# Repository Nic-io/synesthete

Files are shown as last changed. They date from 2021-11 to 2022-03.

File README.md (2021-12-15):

# Synesthete

## Listen to your eyes
A Zephyr RTOS project

This project aims at creating a Eurorack module on the base of Zephyr.

The main functionality is to produce a waveform generated by drawing on
a touch screen.

## Environment 
For a quick start you can use the pre made devcontainer by running
the script here : https://github.com/Nic-io/vittles

## Build

Run ```west build -b nucleo_f446re -- -DSHIELD=adafruit_2_8_tft_touch_v2```

## Hardware
SVG Panel :

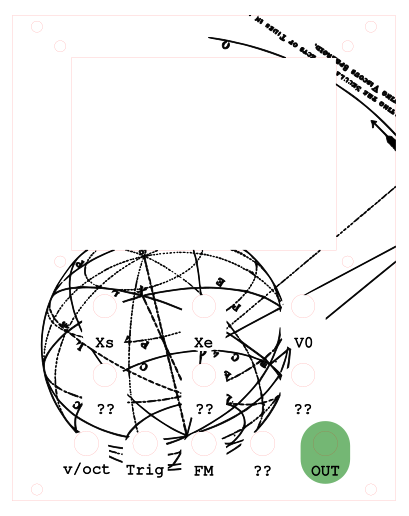
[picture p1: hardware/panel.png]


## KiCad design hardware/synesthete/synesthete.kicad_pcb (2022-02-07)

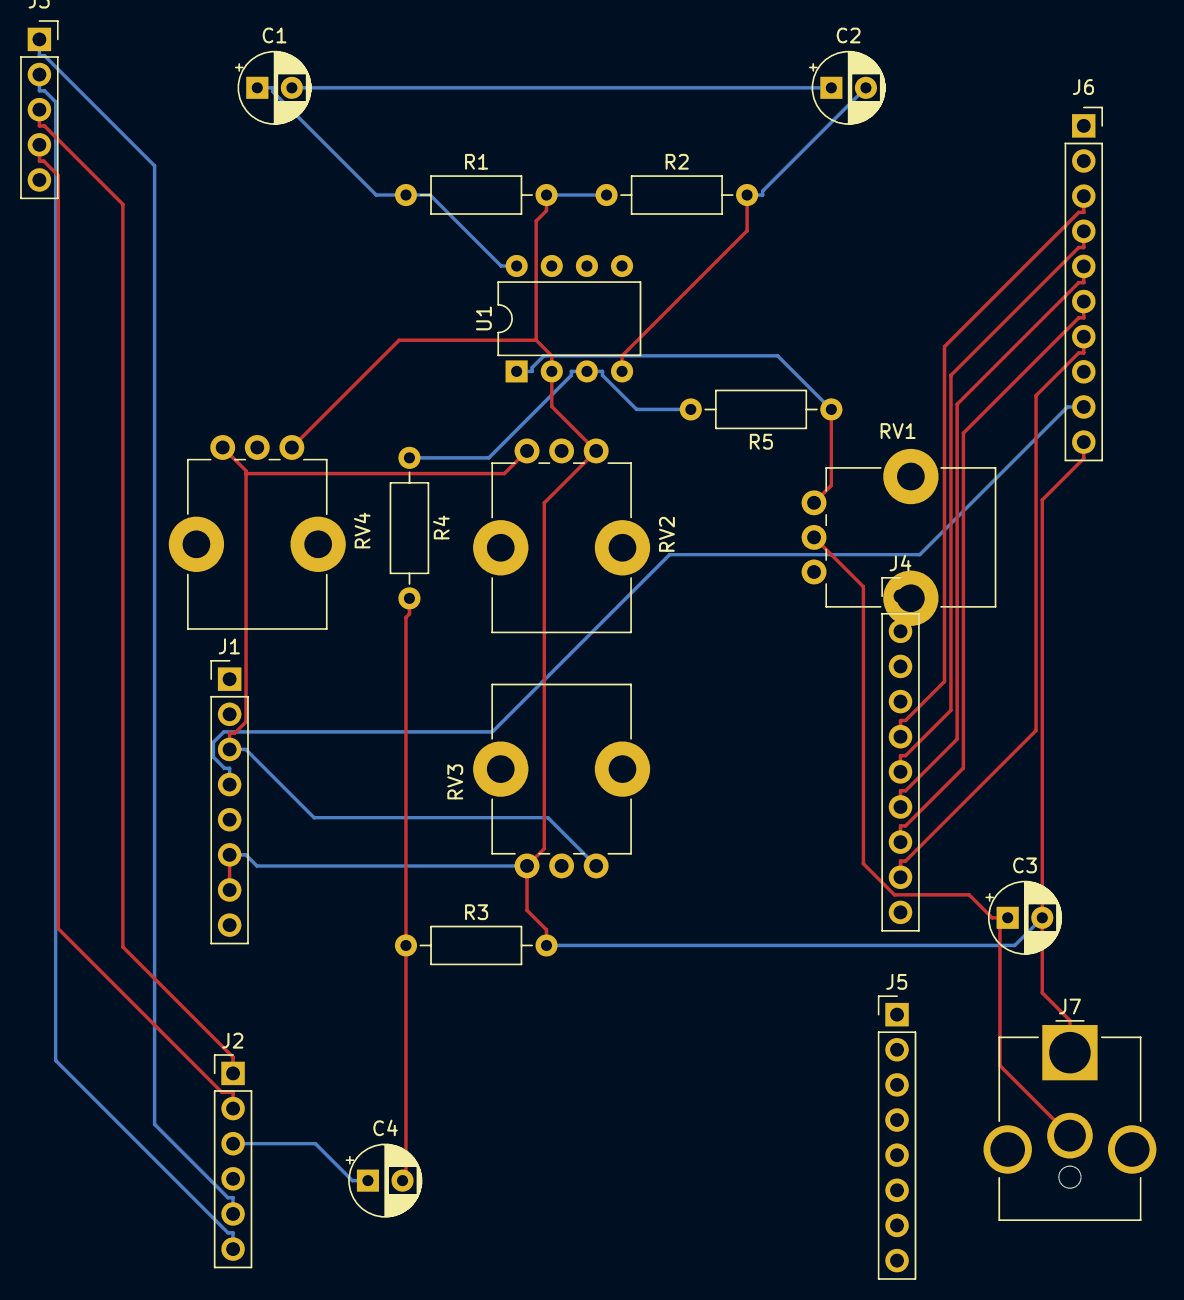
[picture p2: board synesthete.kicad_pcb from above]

Board: 2 copper layers, 21 parts (0 on the bottom side), 20 nets.

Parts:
C1, C2: 47uF; CP_Radial_D5.0mm_P2.50mm
C3: 1uF; CP_Radial_D5.0mm_P2.50mm
C4: 10uF; CP_Radial_D5.0mm_P2.50mm
J1, J5: Conn_01x08_Male; PinHeader_1x08_P2.54mm_Vertical
J2: Conn_01x06_Male; PinHeader_1x06_P2.54mm_Vertical
J3: Conn_01x05_Female; PinSocket_1x05_P2.54mm_Vertical
J4: Conn_01x10_Male; PinHeader_1x10_P2.54mm_Vertical
J6: Conn_01x10_Female; PinSocket_1x10_P2.54mm_Vertical
J7: Jack-DC; BarrelJack_CUI_PJ-063AH_Horizontal_CircularHoles
R1, R2: 47k; R_Axial_DIN0207_L6.3mm_D2.5mm_P10.16mm_Horizontal
R3: 39k; R_Axial_DIN0207_L6.3mm_D2.5mm_P10.16mm_Horizontal
R4: 3.3k; R_Axial_DIN0207_L6.3mm_D2.5mm_P10.16mm_Horizontal
R5: 10k; R_Axial_DIN0207_L6.3mm_D2.5mm_P10.16mm_Horizontal
RV1: 0-10k; Potentiometer_Alps_RK09K_Single_Vertical
RV2, RV3, RV4: R_POT; Potentiometer_Alps_RK09K_Single_Vertical
U1: LM358; DIP-8_W7.62mm

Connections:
+3V3: J1.3, RV2.1, RV3.1, RV4.1
+5V: J1.4, J6.9
/CLK: J4.9, J6.7
/CS: J4.6, J6.4
/DC: J4.5, J6.3
/Miso: J4.8, J6.6
/Mosi: J4.7, J6.5
/dacout: C4.1, J2.3
/x+: J2.2, J3.4
/x-: J2.6, J3.2
/y+: J2.1, J3.3
/y-: J2.5, J3.1
GND: C3.2, J1.6, J1.7, J6.10, J7.1, R1.2, R2.1, R3.2, RV2.3, RV3.3, RV4.3, U1.2
unnamed: C1.2, C2.1
unnamed: C3.1, J7.2, RV1.2
unnamed: C4.2, R3.1, R4.2
unnamed: R4.1, R5.2, U1.3
unnamed: R5.1, RV1.3, U1.1
VCC: C1.1, R1.1, U1.8
VEE: C2.2, R2.2, U1.4

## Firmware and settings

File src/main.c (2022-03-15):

/*
 * Copyright (c) 2021 Nicolas Blazevic <nicolas@ecliptic.fr>
 *
 * SPDX-License-Identifier: Apache-2.0
 */

#include <logging/log.h>
LOG_MODULE_REGISTER(main, LOG_LEVEL_INF);

#include "synesthete.h"
#include <console/console.h>
#include <device.h>
#include <drivers/display.h>
#include <sys/printk.h>
#include <zephyr.h>

#define STACK_SIZE 1024
#define GUI_PRIO 6
#define TABLE_PRIO 1
#define SOUND_PRIO 2

K_THREAD_STACK_DEFINE(gui_stack_area, STACK_SIZE);
K_THREAD_STACK_DEFINE(table_stack_area, STACK_SIZE);
K_THREAD_STACK_DEFINE(soundstack, STACK_SIZE);

k_tid_t my_tid;
k_tid_t my_tid2;
k_tid_t my_tid3;

void gui_thread(void *p1, void *p2, void *p3)
{
	while (1) {
		wave_draw();
		k_msleep(1);
	}
}

void update_table(void *p1, void *p2, void *p3)
{
	while (1) {
		wave_aquire();
		k_sleep(K_USEC(1));
	}
}

void produceSound(void *p1, void *p2, void *p3)
{
	while (1) {
		getfreq();
		k_sleep(K_USEC(10));
	}
}

void main(void)
{
	console_getline_init();
	synesthete_init();

	struct k_thread guiThread;
	my_tid = k_thread_create(&guiThread, gui_stack_area,
				 K_THREAD_STACK_SIZEOF(gui_stack_area),
				 gui_thread, &my_tid2, NULL, NULL, GUI_PRIO, 0,
				 K_NO_WAIT);

	struct k_thread tableThread;
	my_tid2 = k_thread_create(&tableThread, table_stack_area,
				  K_THREAD_STACK_SIZEOF(table_stack_area),
				  update_table, &my_tid, NULL, NULL, TABLE_PRIO,
				  0, K_NO_WAIT);

	struct k_thread soundThread;
	my_tid3 =
		k_thread_create(&soundThread, soundstack,
				K_THREAD_STACK_SIZEOF(soundstack), produceSound,
				&my_tid, NULL, NULL, SOUND_PRIO, 0, K_NO_WAIT);

	while (1) {
		k_msleep(100);
	}
}

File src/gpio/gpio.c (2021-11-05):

/*
 * Copyright (c) 2021 Nicolas Blazevic <nicolas@ecliptic.fr>
 *
 * SPDX-License-Identifier: Apache-2.0
 */

#include "gpio.h"

LOG_MODULE_REGISTER(Synesthete_GPIO, LOG_LEVEL_INF);

/* The devicetree node identifier for the pins. */
#define TOUCHXPOS DT_PATH(touchpins, xpos)
#define TOUCHXNEG DT_PATH(touchpins, xgnd)
#define TOUCHYPOS DT_PATH(touchpins, ypos)
#define TOUCHYNEG DT_PATH(touchpins, ygnd)

#if DT_NODE_HAS_STATUS(TOUCHXPOS, okay) && \
    DT_NODE_HAS_STATUS(TOUCHXNEG, okay) && \
    DT_NODE_HAS_STATUS(TOUCHYPOS, okay) && \
    DT_NODE_HAS_STATUS(TOUCHYNEG, okay)

#define XPOS	DT_GPIO_LABEL(TOUCHXPOS, gpios)
#define PIN_X_P	DT_GPIO_PIN(TOUCHXPOS, gpios)
#define FLAGS_X_P	DT_GPIO_FLAGS(TOUCHXPOS, gpios)

#define XNEG	DT_GPIO_LABEL(TOUCHXNEG, gpios)
#define PIN_X_N	DT_GPIO_PIN(TOUCHXNEG, gpios)
#define FLAGS_X_N	DT_GPIO_FLAGS(TOUCHXNEG, gpios)

#define YPOS	DT_GPIO_LABEL(TOUCHYPOS, gpios)
#define PIN_Y_P	DT_GPIO_PIN(TOUCHYPOS, gpios)
#define FLAGS_Y_P	DT_GPIO_FLAGS(TOUCHYPOS, gpios)

#define YNEG	DT_GPIO_LABEL(TOUCHYNEG, gpios)
#define PIN_Y_N	DT_GPIO_PIN(TOUCHYNEG, gpios)
#define FLAGS_Y_N	DT_GPIO_FLAGS(TOUCHYNEG, gpios)

#else
#error "Unsupported board"
#endif

const struct device *devXpos;
const struct device *devXneg;
const struct device *devYpos;
const struct device *devYneg;

int gpios_init(void){

	devXpos = device_get_binding(XPOS);
    devXneg = device_get_binding(XNEG);
    devYpos = device_get_binding(YPOS);
    devYneg = device_get_binding(YNEG);
    if (devXneg == NULL || devXpos == NULL || devXneg == NULL || devYneg == NULL){
        //LOG_ERR("device initialization failed");
        return 1;
    }

	gpio_pin_set(devXneg, PIN_X_N, 0);
    gpio_pin_set(devYneg, PIN_Y_N, 0);

    return 0;
}

void gpio_set_touchpin(touchPin hPin, int value){
    int ret=0;
    switch(hPin){
        case xpos :
            gpio_pin_configure(devXpos, PIN_X_P, GPIO_OUTPUT_ACTIVE | FLAGS_X_P);
	        ret = gpio_pin_set(devXpos, PIN_X_P, value);
            break;
        case xneg :
            gpio_pin_configure(devXneg, PIN_X_N, GPIO_OUTPUT_ACTIVE | FLAGS_X_N);
	        ret = gpio_pin_set(devXneg, PIN_X_N, value);
            break;
        case ypos :
            gpio_pin_configure(devYpos, PIN_Y_P, GPIO_OUTPUT_ACTIVE | FLAGS_Y_P);
	        ret = gpio_pin_set(devYpos, PIN_Y_P, value);
            break;
        case yneg:
            gpio_pin_configure(devYneg, PIN_Y_N, GPIO_OUTPUT_ACTIVE | FLAGS_Y_N);
	        ret = gpio_pin_set(devYneg, PIN_Y_N, value);
            break;
    }
    if(ret != 0){
        LOG_ERR("GPIO set failed ERRNO =%d", ret);
    }
}

void gpio_disable_touchpin(touchPin tPin){
    int ret=0;
    switch (tPin){
        case xpos :
            ret = gpio_pin_configure(devXpos, PIN_X_P, GPIO_DISCONNECTED);
        case xneg :
            ret = gpio_pin_configure(devXneg, PIN_X_N, GPIO_DISCONNECTED);
        case ypos :
            ret = gpio_pin_configure(devYpos, PIN_Y_P, GPIO_DISCONNECTED);
        case yneg :
            ret = gpio_pin_configure(devYneg, PIN_Y_N, GPIO_DISCONNECTED);
    }
     if(ret != 0){
        LOG_ERR("GPIO set failed ERRNO =%d", ret);
    }
}

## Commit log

2021-10-01 first template from display samples
2021-10-12 Basic sample to start with a screen
2021-10-20 Structurting project, added Threads, preparing ADC for touchScreen
2021-10-26 touch layer added with ADC & GPIOS
2021-11-04 adding HAL from ST for timer control
2021-11-04 DMA needed callback to be set
2021-12-09 patch upstream DAC driver for stm32 to use DMA
2021-12-15 schematic for shield
    [_saved_synesthete.sch, synesthete.kicad_pcb, synesthete.sch]
2022-02-07 add potentiometers lines to schematics
    [_saved_synesthete.sch, synesthete.kicad_pcb, synesthete.sch]
